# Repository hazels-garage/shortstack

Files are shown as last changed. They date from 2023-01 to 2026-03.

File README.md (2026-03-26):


<a href="https://discord.gg/jP6hvgNN8r">
  
</a>

# shortstack

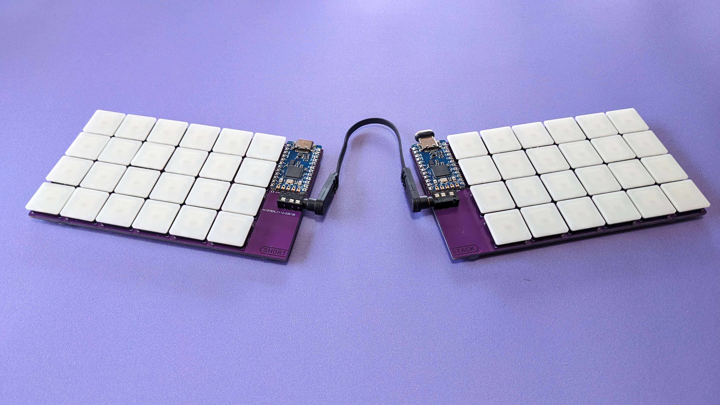
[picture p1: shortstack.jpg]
build


| Left | Right |
| :---: | :---: |
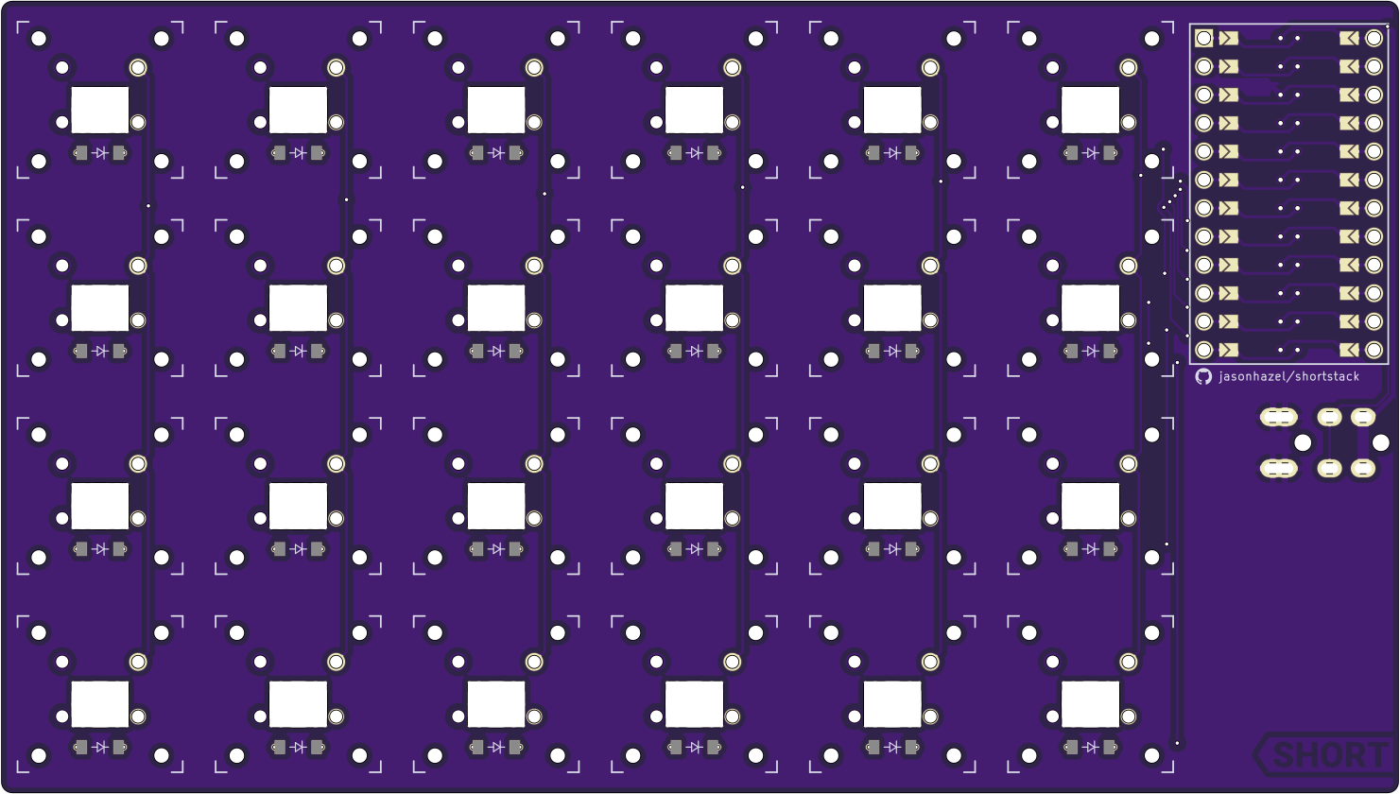
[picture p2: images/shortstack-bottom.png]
left
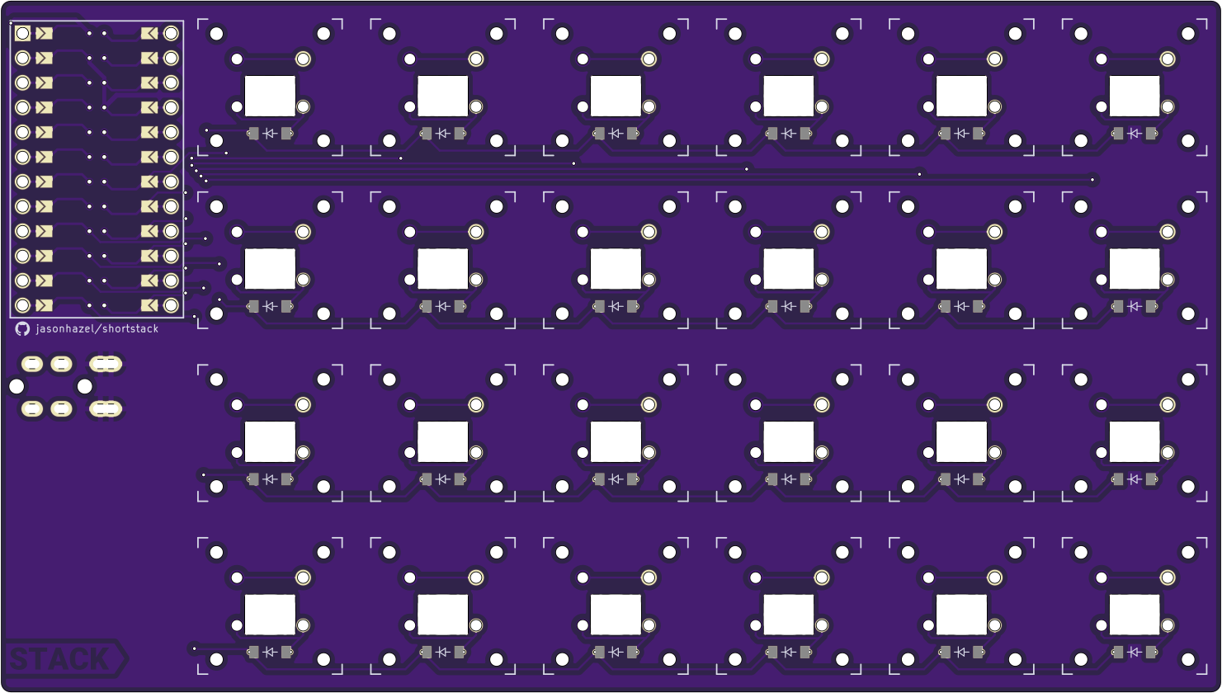
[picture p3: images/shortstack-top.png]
right
|   |  |

## ultrathin split ortholinear

Probably my final X Switch novelty board.  Split 6x4 ortho.  No bells or whistles.

## MATERIALS
- 48x [Kailh X Switches](https://mkultra.click/kailh-x-switches-and-keycaps/)
- 48x [1N4148 - SOD-123 Diodes](https://mkultra.click/diode-1n4148-sod-123f/)
- 2x ProMicro compatible controller
- 2x [TRRS Jack](https://mkultra.click/pj-320a-3-5mm-trrs-jack/)

## Build Details
- reversible pcb.
- solder jumpers on back of each side.
- controller is installed component side up.
- right side is connected to computer.

## FIRMWARE

[QMK](https://github.com/jasonhazel/qmk_hazel/tree/master/keyboards/jasonhazel/shortstack)

## SUPPORT
<a href='https://discord.gg/jP6hvgNN8r'>
Discord Shield
</a>

<p xmlns:cc="http://creativecommons.org/ns#" xmlns:dct="http://purl.org/dc/terms/"><a property="dct:title" rel="cc:attributionURL" href="https://github.com/jasonhazel/shortstack">shortstack</a> by <a rel="cc:attributionURL dct:creator" property="cc:attributionName" href="https://github.com/jasonhazel">Jason Hazel</a> is licensed under <a href="http://creativecommons.org/licenses/by/4.0/?ref=chooser-v1" target="_blank" rel="license noopener noreferrer" style="display:inline-block;">CC BY 4.0</a></p>

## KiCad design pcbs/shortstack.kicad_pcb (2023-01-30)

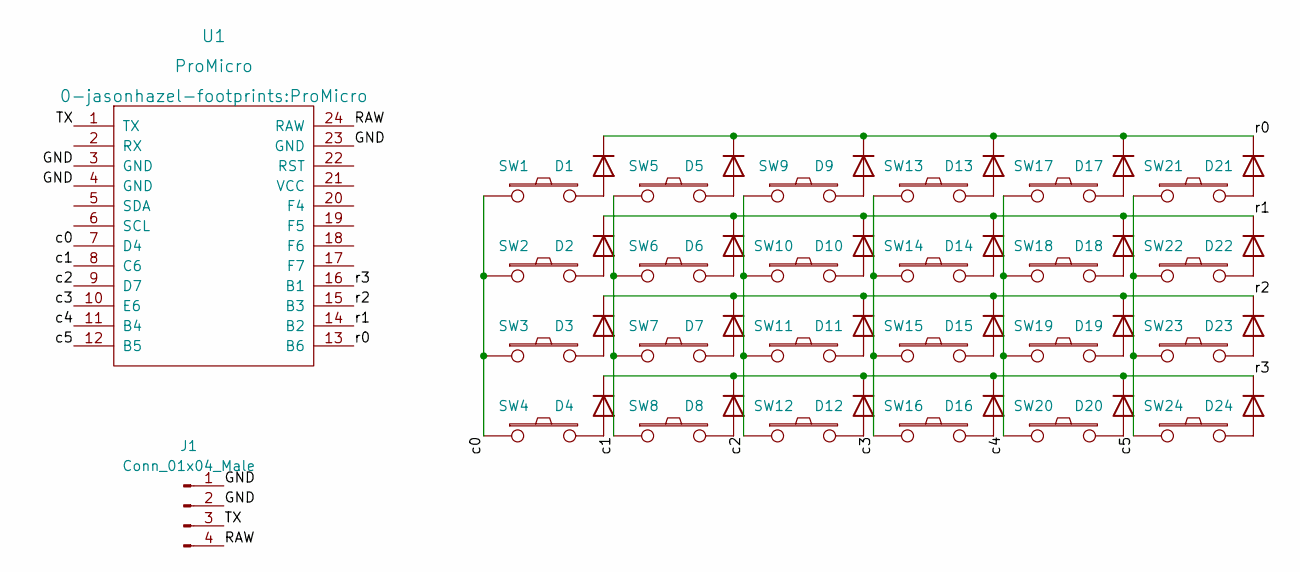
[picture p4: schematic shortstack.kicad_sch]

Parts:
D1, D2, D3, D4, D5, D6, D7, D8, D9, D10, D11, D12, D13, D14, D15, D16, D17, D18, D19, D20, D21, D22, D23, D24: 1N4148W; D_SOD-123-rev
J1: Conn_01x04_Male; TRRS-PJ-320A-dual
SW1, SW2, SW3, SW4, SW5, SW6, SW7, SW8, SW9, SW10, SW11, SW12, SW13, SW14, SW15, SW16, SW17, SW18, SW19, SW20, SW21, SW22, SW23, SW24: SW_PUSH; Kailh-PG1425-X-Switch-revers
U1: ProMicro

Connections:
/GND: J1.1, J1.2, U1.3 (GND), U1.4 (GND), U1.23 (GND)
/RAW: J1.4, U1.24 (RAW)
/TX: J1.3, U1.1 (TX)
/c0: SW1.1, SW2.1, SW3.1, SW4.1, U1.7 (D4)
/c1: SW5.1, SW6.1, SW7.1, SW8.1, U1.8 (C6)
/c2: SW9.1, SW10.1, SW11.1, SW12.1, U1.9 (D7)
/c3: SW13.1, SW14.1, SW15.1, SW16.1, U1.10 (E6)
/c4: SW17.1, SW18.1, SW19.1, SW20.1, U1.11 (B4)
/c5: SW21.1, SW22.1, SW23.1, SW24.1, U1.12 (B5)
/r0: D1.1 (K), D5.1 (K), D9.1 (K), D13.1 (K), D17.1 (K), D21.1 (K), U1.13 (B6)
/r1: D2.1 (K), D6.1 (K), D10.1 (K), D14.1 (K), D18.1 (K), D22.1 (K), U1.14 (B2)
/r2: D3.1 (K), D7.1 (K), D11.1 (K), D15.1 (K), D19.1 (K), D23.1 (K), U1.15 (B3)
/r3: D4.1 (K), D8.1 (K), D12.1 (K), D16.1 (K), D20.1 (K), D24.1 (K), U1.16 (B1)
unnamed: D1.2 (A), SW1.2
unnamed: D2.2 (A), SW2.2
unnamed: D3.2 (A), SW3.2
unnamed: D4.2 (A), SW4.2
unnamed: D5.2 (A), SW5.2
unnamed: D6.2 (A), SW6.2
unnamed: D7.2 (A), SW7.2
unnamed: D8.2 (A), SW8.2
unnamed: D9.2 (A), SW9.2
unnamed: D10.2 (A), SW10.2
unnamed: D11.2 (A), SW11.2
unnamed: D12.2 (A), SW12.2
unnamed: D13.2 (A), SW13.2
unnamed: D14.2 (A), SW14.2
unnamed: D15.2 (A), SW15.2
unnamed: D16.2 (A), SW16.2
unnamed: D17.2 (A), SW17.2
unnamed: D18.2 (A), SW18.2
unnamed: D19.2 (A), SW19.2
unnamed: D20.2 (A), SW20.2
unnamed: D21.2 (A), SW21.2
unnamed: D22.2 (A), SW22.2
unnamed: D23.2 (A), SW23.2
unnamed: D24.2 (A), SW24.2

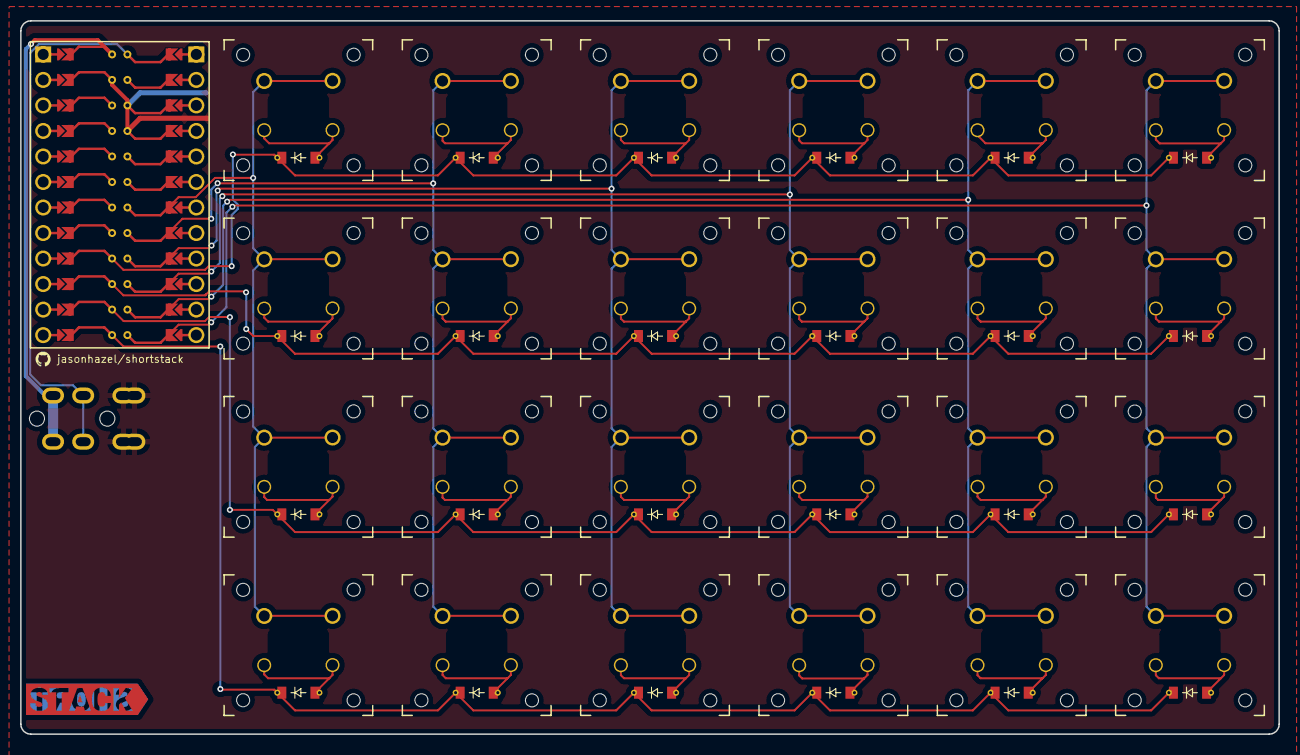
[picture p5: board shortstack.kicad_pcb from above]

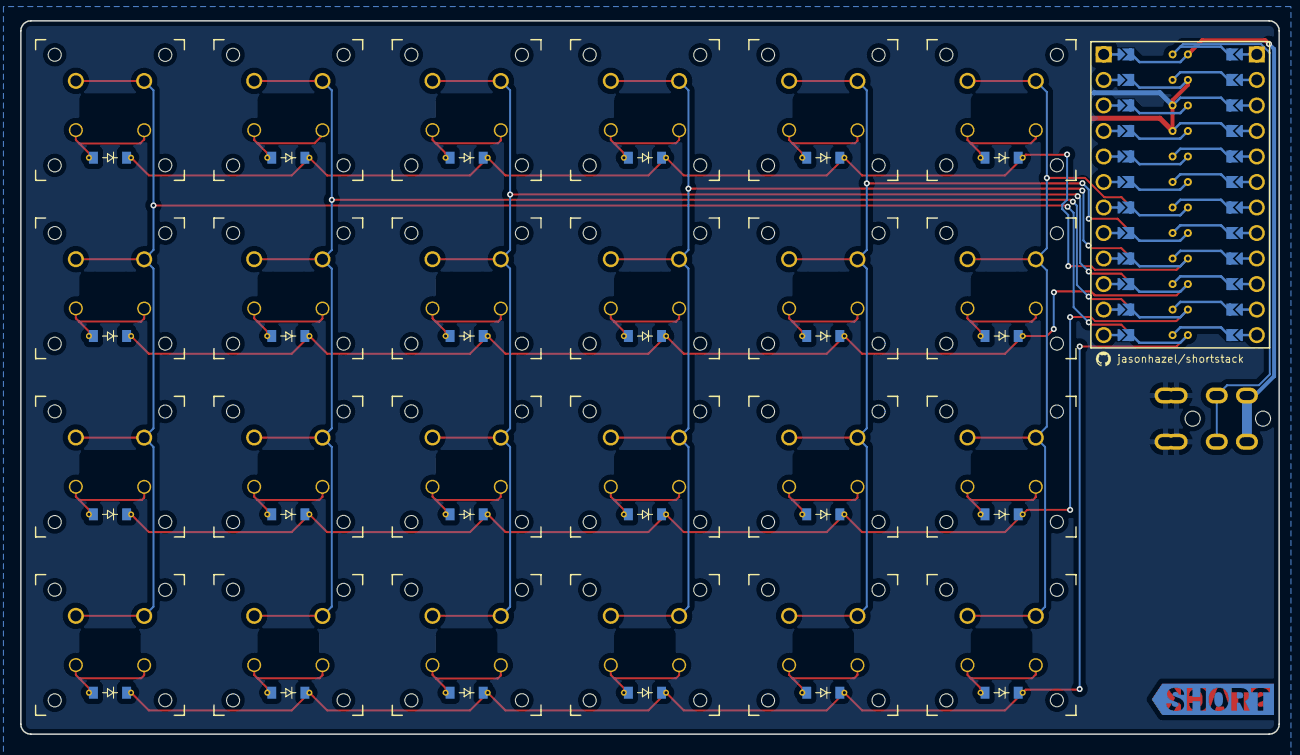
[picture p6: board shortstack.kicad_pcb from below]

Board: 2 copper layers, 125.2 x 71.0 mm, 54 parts (26 on the bottom side), 37 nets.

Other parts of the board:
GH2, GH2#2: jasonhazel/shortstack; github
kibuzzard-63D71E25: G***; kibuzzard-63D71E25
kibuzzard-63D71F2F: G***; kibuzzard-63D71F2F

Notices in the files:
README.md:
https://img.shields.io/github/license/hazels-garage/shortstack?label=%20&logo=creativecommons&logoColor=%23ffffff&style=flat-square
